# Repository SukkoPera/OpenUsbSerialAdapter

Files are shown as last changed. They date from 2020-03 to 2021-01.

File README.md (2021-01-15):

# OpenUsbSerialAdapter
OpenUsbSerialAdapter is an Open Hardware USB to TTL-level Serial converter.

Board

### Summary
An infinite number of different models of USB to TTL-level serial converters can be found on every online shop, many of which even cost less than 1€ shipped from China, so why make one more? There are a few reasons:
- Many of them are missing the DTR and RTS signals (or at least do not break them out so that they can be used). At least one of these signals is necessary for programming Arduino boards through the serial port and, since this makes up for 90% of my use of USB to serial converters, I find this pretty annoying.
- Most of these cheap converters claim to be both 5V and 3.3V serial level compatible, but all most of them actually do is just use 3.3V signalling, which *usually* also works fine with boards that work at 5V, but still it is a bit of a hack.
- None of these converters has a decent 3.3V regulator onboard, usually being able to provide only a few tens of milliamperes on the 3.3V power pin (and not even all of them have one). This is too little for some uses, like powering an ESP8266 module for instance, and is the source of maaany of the problems users report with that chip.
- Finding Windows and OSX drivers for some of these modules is a nightmare.
- Not to mention the infamous FTDI-gate...

So, when I came across a USB to Serial chip ([Microchip MCP2200](http://ww1.microchip.com/downloads/en/DeviceDoc/200022228D.pdf)) that had RTS/CTS signals and claimed not to need any particular drivers, I decided to have a go at designing the one converter to rule them all. I tried to consider every possible feature during the design, but in any case I am releasing this as Open Hardware, so everybody can customize it so that it fully suits their needs.

### Features
- Real support for both 3.3V and 5V signalling and power output levels
- RX/TX leds
- Protection resistors for RX/TX inversion
- RX/TX pull-up resistors (optional)
- Can provide up to 1A current on the 3.3V power output pin (This will actually be less as it will be limited by USB)
- Hardware Flow Control pins (RTS/CTS, RTS can be used for the initial reset for Arduino programming)
- Speed up to 1000 kBaud/s
- Uses USB HID capabilities, which means it needs no drivers on Windows/OSX (This has to confirmed, as I only run Linux)
- Configurable product/manufacturer strings and PID/VID
- Ability to invert the polarity of the RX/TX signals
- Compact form factor (about the size of a standard thumb drive)
- Cheap (total BOM cost is less than 3€) and easy to DIY-build (about 20 common components, SMD soldering ability is required, but all components are 0805 or larger)

### Assembly and Configuration
Solder all components to the board in the order you prefer. You have some options:
- R3 and R4 are the RX/TX inversion protection resistors. I used 100 ohm for these, which works fine in my tests, but this value was improvised rather than calculated. You might want to increase them up to 1k for additional safety. In rare cases, you might want to replace them with 0 ohm/solder blobs, but this might be harmful for the main chip or for the device it is connected to. Do this at your risk.
- R5 and R6 are the RX/TX pull-up resistors. Usually these are not necessary, so you might want to skip them. Note that R7 is mandatory instead.

The adapter is somewhat configurable. On Windows you can use [the official Microchip Configuration Utility](http://ww1.microchip.com/downloads/en/DeviceDoc/MCP2200%20Configuration%20Utility%20v1.3.1.zip). On Linux (and OSX?) you can use [a quick replacement I put together](https://github.com/SukkoPera/OpenUsbSerialAdapter/tree/master/confutil), or [this other one](https://github.com/andrasbiro/mcp2200hid-linux). The latter is also capable of changing the USB product/manufacturer strings and PID/VID.

Note that the factory settings of the chip will NOT make the RX/TX leds blink on traffic, you will have to enable that through the configuration utility. Another apparent oddity is that you need to turn Hardware Flow Control OFF in order to use the adapter for Arduino programming.

Signal polarity inversion can also be enabled through the Configuration Utility.

### Usage
Just plug the converter into a free USB port of your computer. On Linux a /dev/ttyACMx device should pop up within seconds. On other Operating Systems... You are on your own :). In theory, it should not need any dedicated drivers, but I saw there are some [on the MCP2200 product page](https://www.microchip.com/wwwproducts/en/en546923), so you can get them from there, in case.

### Releases
If you want to get this board produced, you are recommended to get [the latest release](https://github.com/SukkoPera/OpenUsbSerialAdapter/releases) rather than the current git version, as the latter might be under development and is not guaranteed to be working.

Every release is accompanied by its Bill Of Materials (BOM) file and any relevant notes about it, which you are recommended to read carefully.

### License
The OpenUsbSerialAdapter documentation, including the design itself, is copyright &copy; SukkoPera 2020.

OpenUsbSerialAdapter is Open Hardware licensed under the [CERN OHL v. 1.2](http://ohwr.org/cernohl).

You may redistribute and modify this documentation under the terms of the CERN OHL v.1.2. This documentation is distributed *as is* and WITHOUT ANY EXPRESS OR IMPLIED WARRANTIES whatsoever with respect to its functionality, operability or use, including, without limitation, any implied warranties OF MERCHANTABILITY, SATISFACTORY QUALITY, FITNESS FOR A PARTICULAR PURPOSE or infringement. We expressly disclaim any liability whatsoever for any direct, indirect, consequential, incidental or special damages, including, without limitation, lost revenues, lost profits, losses resulting from business interruption or loss of data, regardless of the form of action or legal theory under which the liability may be asserted, even if advised of the possibility or likelihood of such damages.

A copy of the full license is included in file [LICENSE.pdf](LICENSE.pdf), please refer to it for applicable conditions. In order to properly deal with its terms, please see file [LICENSE_HOWTO.pdf](LICENSE_HOWTO.pdf).

The contact points for information about manufactured Products (see section 4.2) are listed in file [PRODUCT.md](PRODUCT.md).

Any modifications made by Licensees (see section 3.4.b) shall be recorded in file [CHANGES.md](CHANGES.md).

The Documentation Location of the original project is https://github.com/SukkoPera/OpenUsbSerialAdapter/.

### Support the Project
If you want to support the project, you can order the boards from PCBWay through this link:

PCB from PCBWay (https://www.pcbway.com/project/shareproject/OpenUsbSerialAdapter_V2.html)

You get my gratitude and cheap, good quality PCBs, professionally-made. I get some credit that will help with this and [other projects](https://www.pcbway.com/project/member/shareproject/?bmbid=41100). You won't even have to worry about the various PCB options, it's all pre-configured for you!

If you still have to register to that site, [you can use this link](https://www.pcbway.com/setinvite.aspx?inviteid=41100) to get some bonus initial credit (and yield me some more).

You can also buy me a coffee if you want:

<a href='https://ko-fi.com/L3L0U18L' target='_blank'>Buy Me a Coffee at ko-fi.com</a>

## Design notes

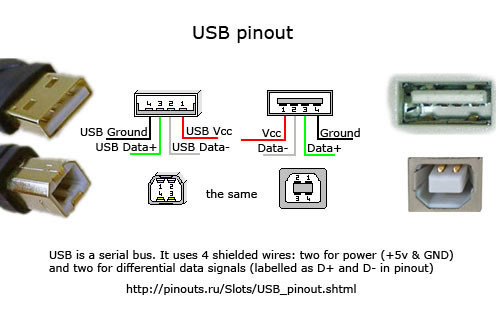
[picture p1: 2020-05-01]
doc/usb-pinout.jpg

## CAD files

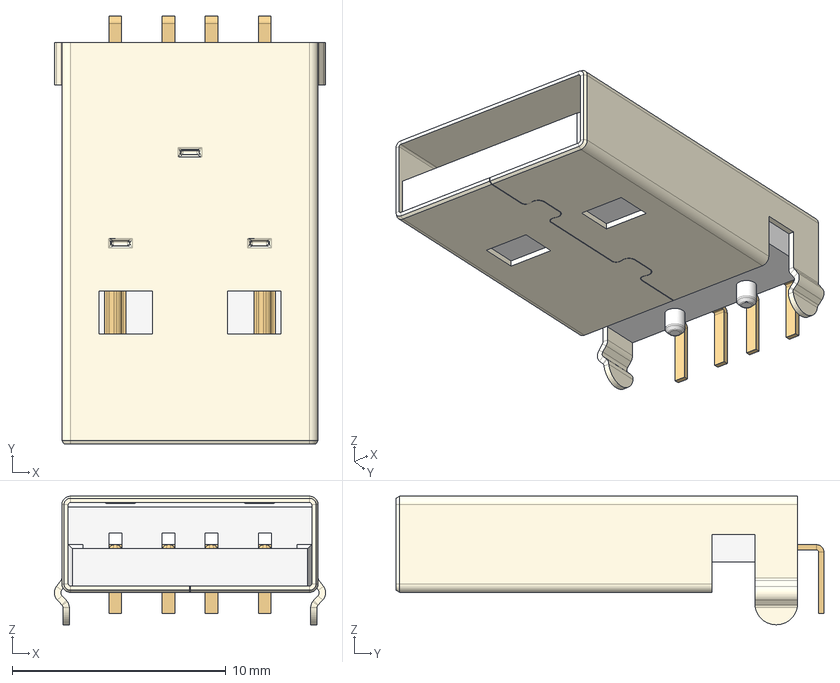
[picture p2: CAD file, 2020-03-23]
3dModels/USB-A Right Angle Solder Plug.stp
12.7 x 20.0 x 6.02 mm
USB-A Right Angle Solder Plug Shell
USB-A Right Angle Solder Plug Inlay
USB-A Right Angle Solder Plug Contact 1 x 2
USB-A Right Angle Solder Plug Contact 2 x 2

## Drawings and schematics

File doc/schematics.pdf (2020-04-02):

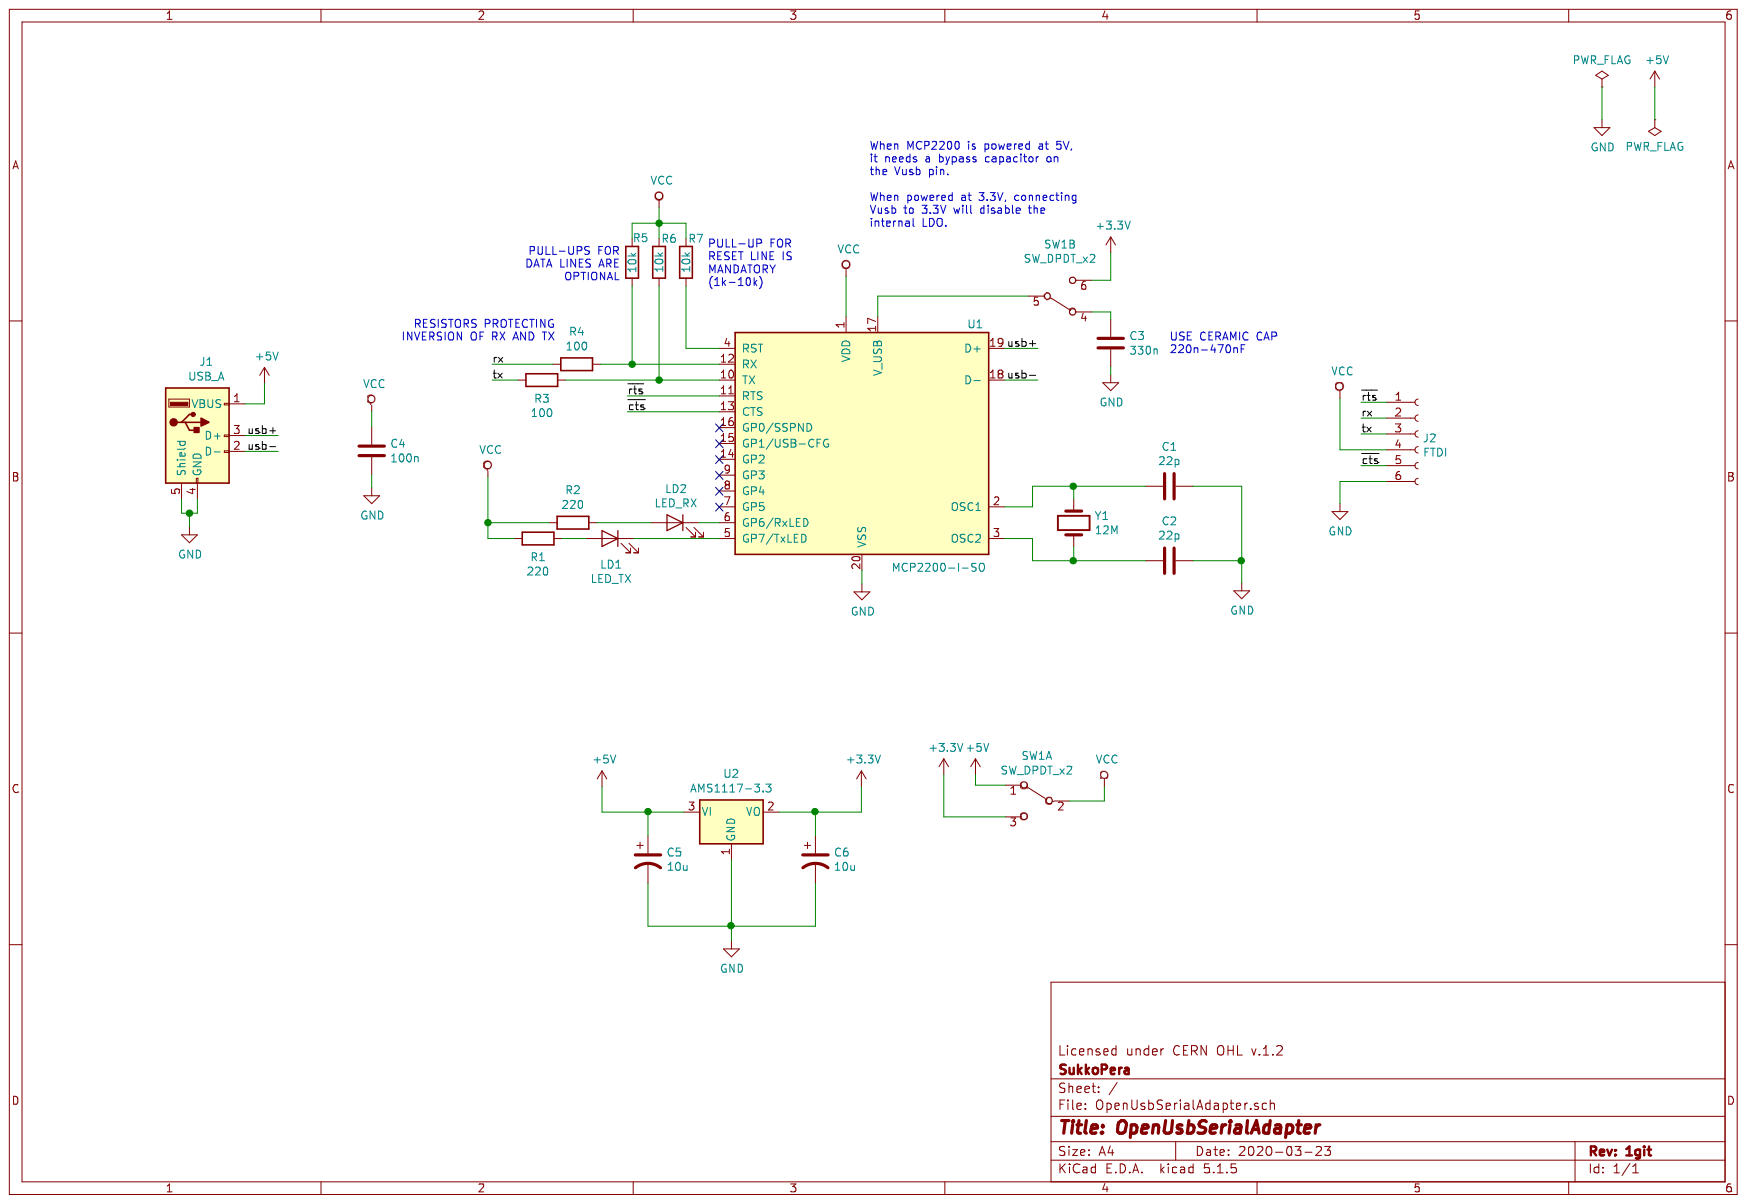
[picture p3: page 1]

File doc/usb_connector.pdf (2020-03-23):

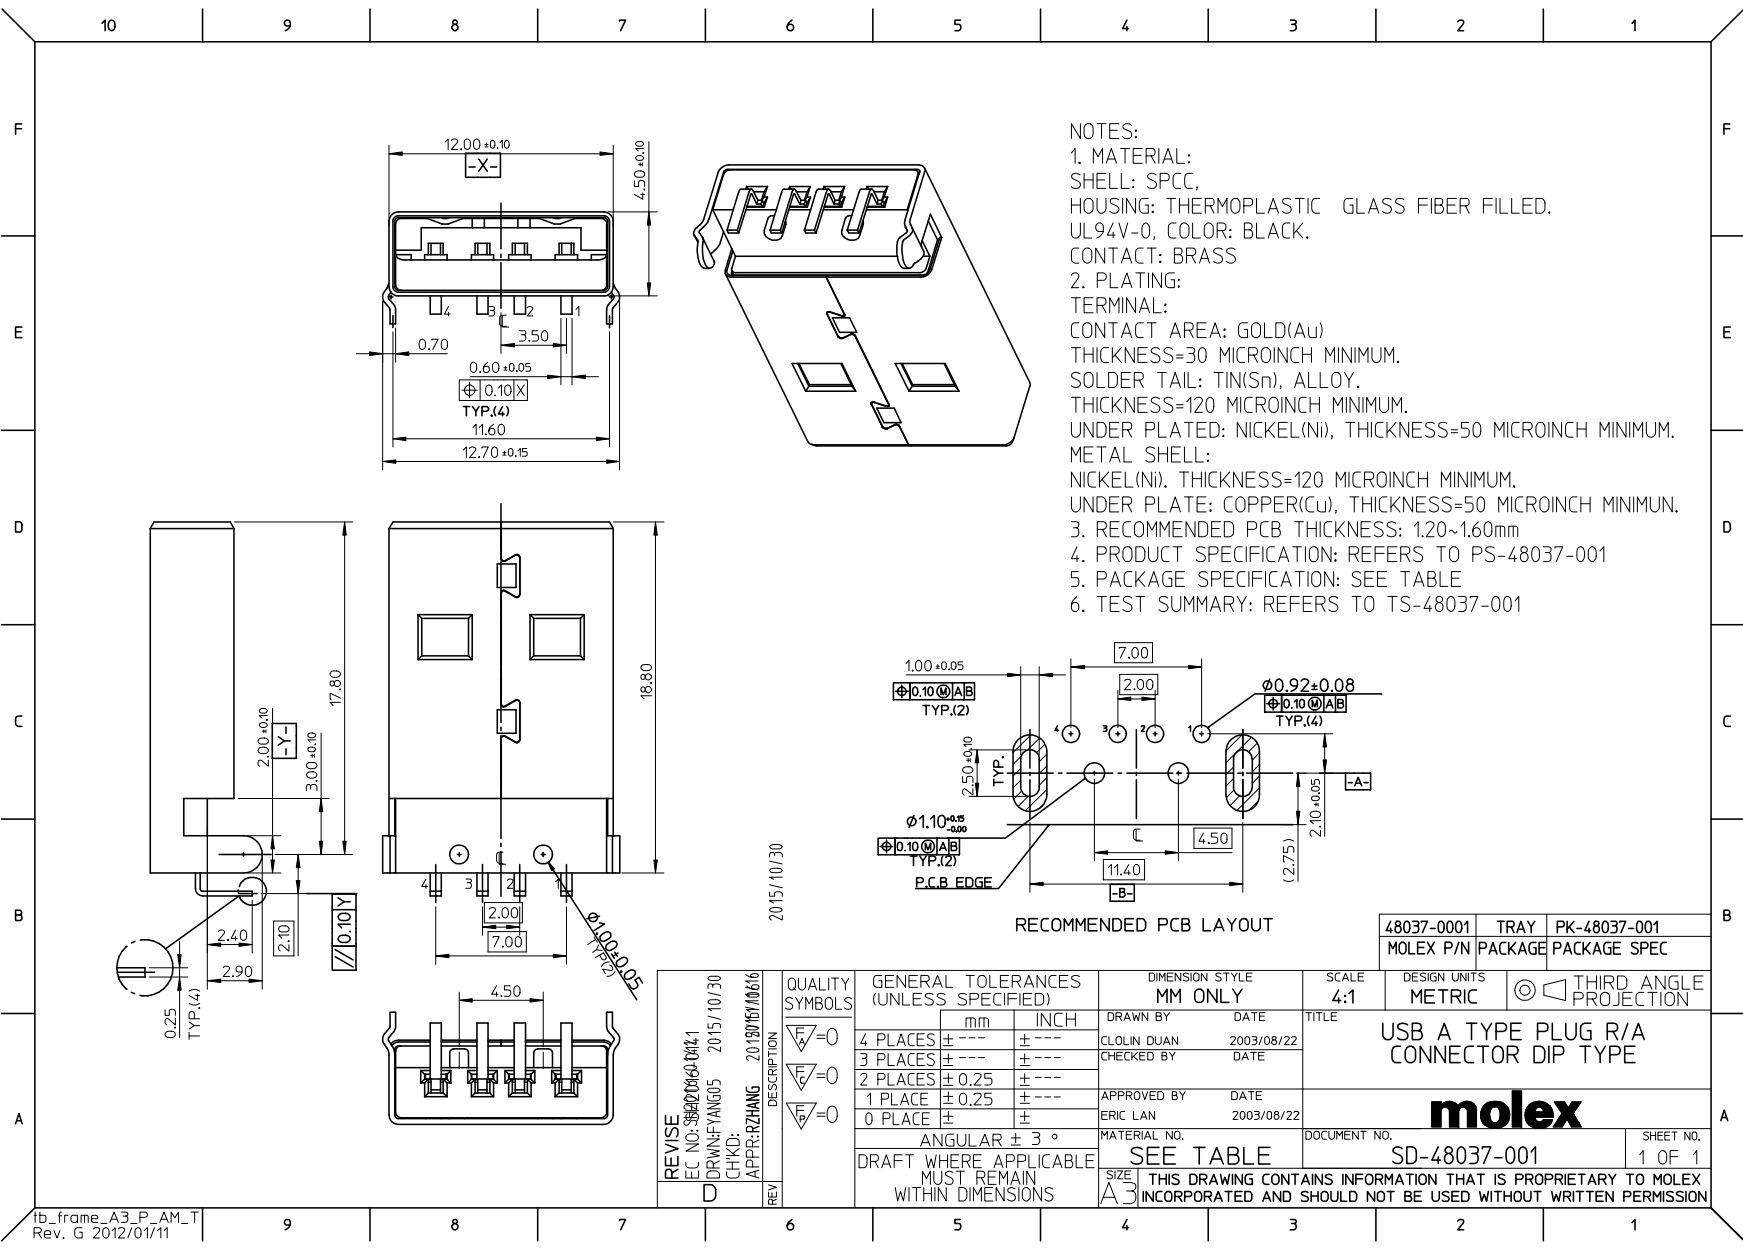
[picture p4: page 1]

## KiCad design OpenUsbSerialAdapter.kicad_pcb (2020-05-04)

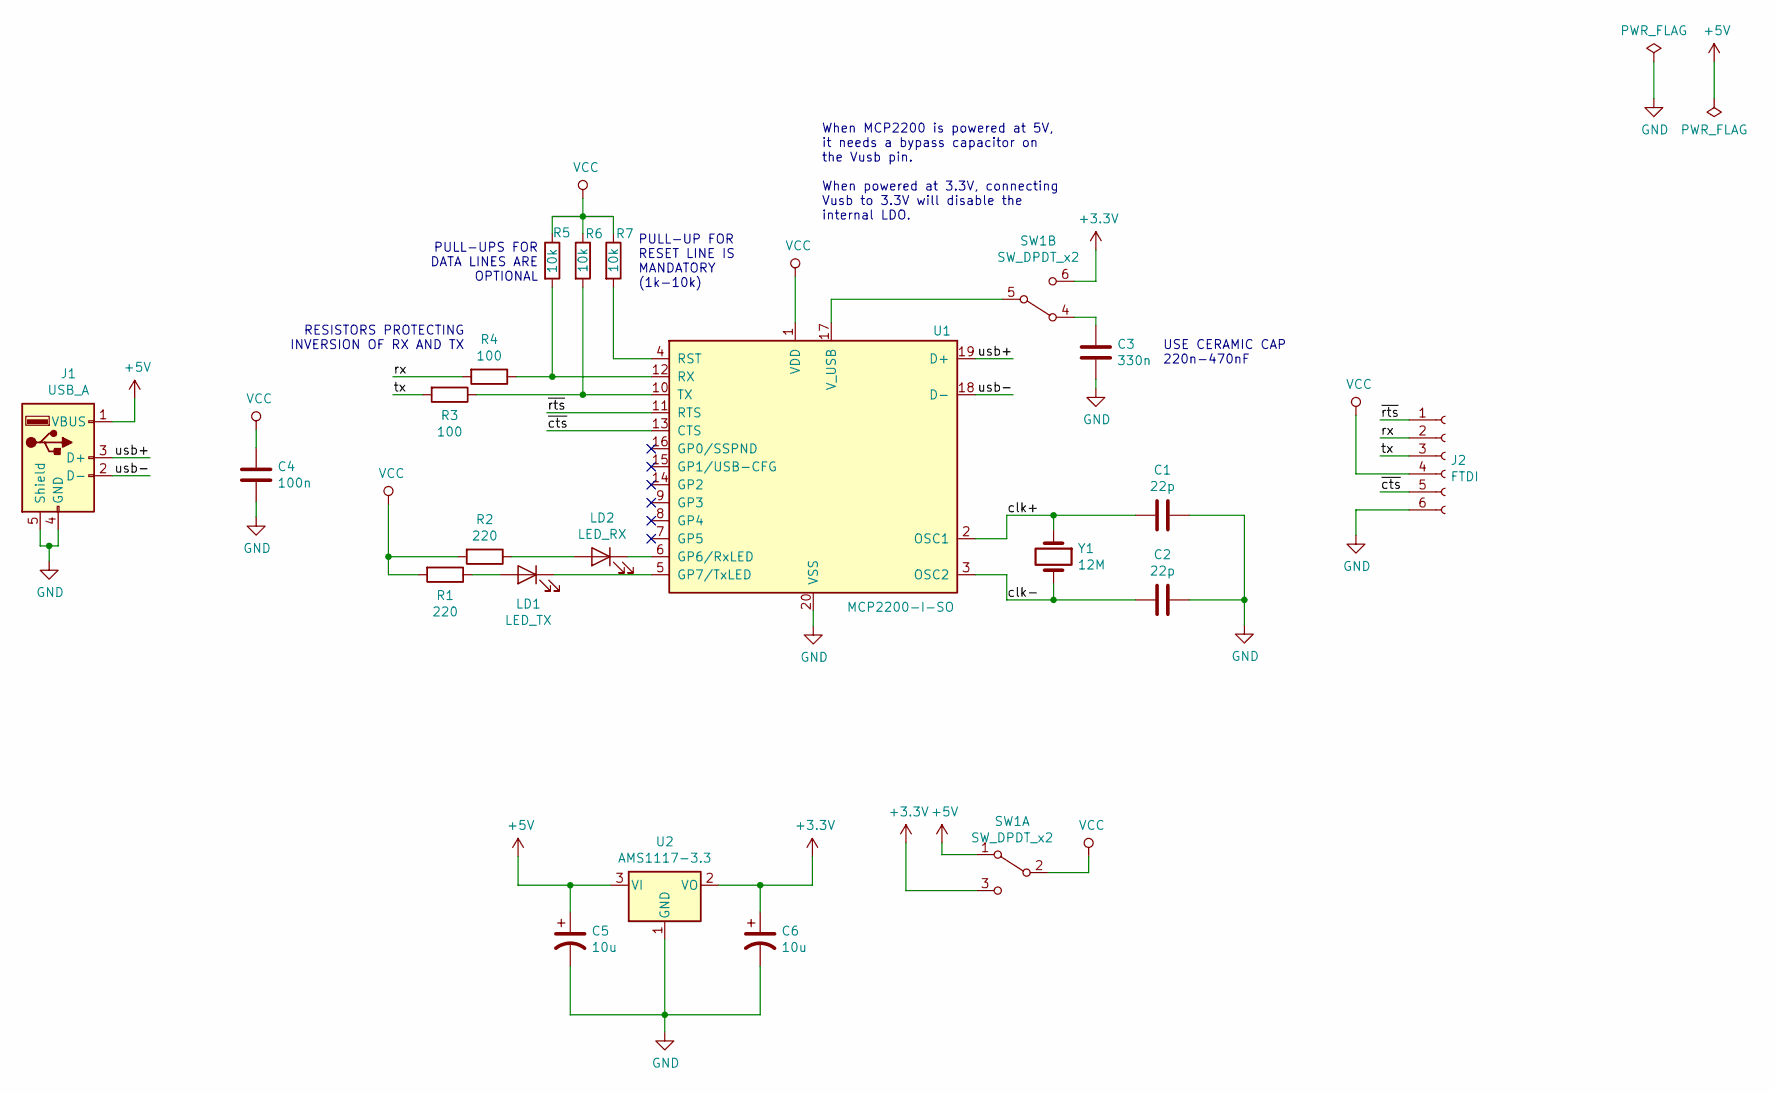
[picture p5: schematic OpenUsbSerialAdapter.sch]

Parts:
C1, C2: 22p; C_0805_2012Metric_Pad1.15x1.40mm_HandSolder
C3: 330n; C_1206_3216Metric_Pad1.42x1.75mm_HandSolder
C4: 100n; C_0805_2012Metric_Pad1.15x1.40mm_HandSolder
C5, C6: 10u; CP_EIA-3216-18_Kemet-A_Pad1.58x1.35mm_HandSolder
J1: USB_A; USB_A_Molex_48037
J2: FTDI; PinHeader_1x06_P2.54mm_Vertical
LD1: LED_TX; LED_0805_2012Metric_Pad1.15x1.40mm_HandSolder
LD2: LED_RX; LED_0805_2012Metric_Pad1.15x1.40mm_HandSolder
R1, R2: 220; R_0805_2012Metric_Pad1.15x1.40mm_HandSolder
R3, R4: 100; R_0805_2012Metric_Pad1.15x1.40mm_HandSolder
R5, R6, R7: 10k; R_0805_2012Metric_Pad1.15x1.40mm_HandSolder
SW1: SW_DPDT_x2; SW_DPDT
U1: MCP2200-I-SO; SOIC-20W_7.5x12.8mm_P1.27mm
U2: AMS1117-3.3; SOT-223-3_TabPin2
Y1: 12M; Crystal_HC49-U_Vertical

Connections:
+3V3: C6.1, SW1.3 (C), SW1.6 (C), U2.2 (VO)
+5V: C5.1, J1.1 (VBUS), SW1.1 (A), U2.3 (VI)
/clk+: C1.2, U1.2 (OSC1), Y1.1
/clk-: C2.2, U1.3 (OSC2), Y1.2
/rx: J2.2, R4.2
/tx: J2.3, R3.2
/usb+: J1.3 (D+), U1.19 (D+)
/usb-: J1.2 (D-), U1.18 (D-)
/~cts: J2.5, U1.13 (CTS)
/~rts: J2.1, U1.11 (RTS)
GND: C1.1, C2.1, C3.2, C4.2, C5.2, C6.2, J1.4 (GND), J1.5 (Shield), J2.6, U1.20 (VSS), U2.1 (GND)
unnamed: C3.1, SW1.4 (A)
unnamed: LD1.1 (K), U1.5 (GP7/TxLED)
unnamed: LD1.2 (A), R1.1
unnamed: LD2.1 (K), U1.6 (GP6/RxLED)
unnamed: LD2.2 (A), R2.1
unnamed: R3.1, R6.2, U1.10 (TX)
unnamed: R4.1, R5.2, U1.12 (RX)
unnamed: R7.2, U1.4 (RST)
unnamed: SW1.5 (B), U1.17 (V_USB)
VCC: C4.1, J2.4, R1.2, R2.2, R5.1, R6.1, R7.1, SW1.2 (B), U1.1 (VDD)

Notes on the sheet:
PULL-UPS FOR DATA LINES ARE OPTIONAL
RESISTORS PROTECTING INVERSION OF RX AND TX
PULL-UP FOR RESET LINE IS MANDATORY (1k-10k)
USE CERAMIC CAP 220n-470nF
When MCP2200 is powered at 5V, it needs a bypass capacitor on the Vusb pin. When powered at 3.3V, connecting Vusb to 3.3V will disable the internal LDO.

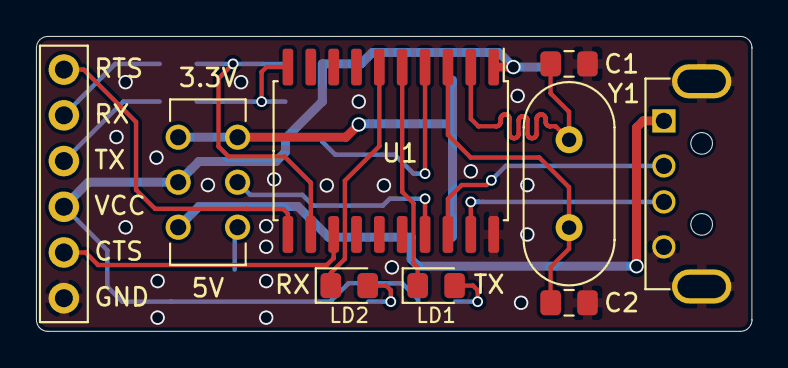
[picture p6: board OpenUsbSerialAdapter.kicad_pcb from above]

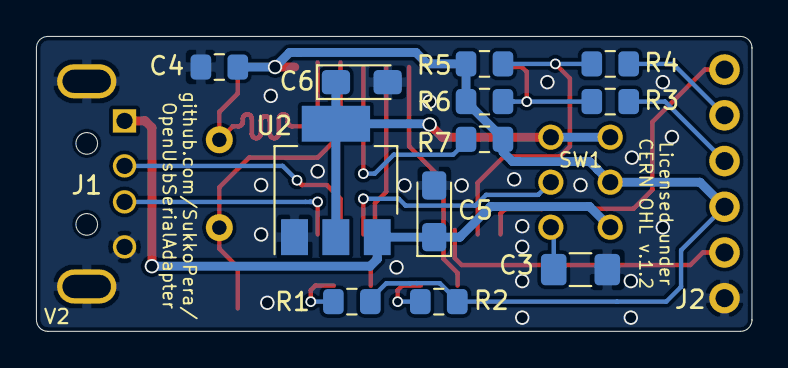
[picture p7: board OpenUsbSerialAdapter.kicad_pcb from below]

Board: 2 copper layers, 39.8 x 16.4 mm, 21 parts (12 on the bottom side), 21 nets.

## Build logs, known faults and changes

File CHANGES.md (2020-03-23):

## CHANGES

Any modifications to the OpenUsbSerialAdapter design and documentation made by any Licensee MUST be noted in this file, as per *section 3.4.b* of the [license](LICENSE.pdf).

### (Date) - (Author)
(Description)

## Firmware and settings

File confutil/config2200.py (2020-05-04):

#!/usr/bin/env python3

# This program was made using information presented in MCP doc
# It can manipulate all the chip features except:
# - Vendor ID
# - Product ID
# - Manufacturer String
# - Product String
#
# as no instruction are presented about how to do this

import sys
import argparse

import hid

vid = 0x04d8
pid = 0x00df

CLOCK_HZ = 12000000

# Config_Alt_Options
CAO_HWFLOW = 0
CAO_INVERT = 1
CAO_LEDX = 5
CAO_TXTGL = 6
CAO_RXTGL = 7

# Config_Alt_Pins
CAP_TXLED = 2
CAP_RXLED = 3
CAP_USBCFG = 6
CAP_SSPND = 7

parser = argparse.ArgumentParser (description = 'MCP2200 Configuration Utility', epilog = "Options take \"on\" or \"off\" values except where noted")
parser.add_argument ('-f', '--flow', type = str, help = 'Hardware Flow Control (CTS/RTS, turn OFF for Arduino programming)')
parser.add_argument ('-i', '--invert', type = str, help = 'Level Inversion')
parser.add_argument ('-s', '--suspend', type = str, help = 'Suspend Pin')
parser.add_argument ('-u', '--usbcfg', type = str, help = 'USB Configured Pin')
parser.add_argument ('-l', '--leds', type = str, help = 'Led Pins Behaviour (off, slow, fast, toggle)')
parser.add_argument ('-b', '--baudrate', type = str, help = 'Serial speed to be used')
args = parser.parse_args ()

def val2bool (v):
	return True if v.lower () == "on" else False

with hid.Device (vid, pid) as h:
	print (f'Device manufacturer: {h.manufacturer}')
	print (f'Product: {h.product}')
	print (f'Serial Number: {h.serial}')

	# Read conf
	h.write (bytes ([0x80] + [0x00] * 15))
	rep = h.read (16)
	if rep[0] != 0x80:
		print ("Bad reply: %s" % str (rep))
	else:
		ioBmap = rep[4]
		confAltPins = rep[5]
		ioDefVal = rep[6]
		confAltOpts = rep[7]
		div = (rep[8] << 8) | rep[9]
		baud = CLOCK_HZ / (div + 1)
		ioPortVal = rep[10]

		print ("Hardware Flow Control: %s" % ("Enabled" if confAltOpts & (1 << CAO_HWFLOW) else "Disabled"))
		print ("Level Inversion: %s" % ("Enabled" if confAltOpts & (1 << CAO_INVERT) else "Disabled"))
		print ("GP0 Function: %s" % ("USB Suspend Signal" if confAltPins & (1 << CAP_SSPND) else "GPIO"))
		print ("GP1 Function: %s" % ("USB Configured Signal" if confAltPins & (1 << CAP_USBCFG) else "GPIO"))
		print ("GP6 Function: %s" % ("RXLED" if confAltPins & (1 << CAP_RXLED) else "GPIO"))
		print ("GP7 Function: %s" % ("TXLED" if confAltPins & (1 << CAP_TXLED) else "GPIO"))
		print ("GPIO Bitmap (0 = out, 1 = in): {0:08b}".format (ioBmap))
		print ("Default GPIO Values (0 = low, 1 = high): {0:08b}".format (ioDefVal))
		print ("Current GPIO Values (0 = low, 1 = high): {0:08b}".format (ioPortVal))
		print ("RX Led: %s" % ("Toggle" if confAltOpts & (1 << CAO_RXTGL) else "Blink %s" % ("slow" if confAltOpts & (1 << CAO_LEDX) else "fast")))
		print ("TX Led: %s" % ("Toggle" if confAltOpts & (1 << CAO_TXTGL) else "Blink %s" % ("slow" if confAltOpts & (1 << CAO_LEDX) else "fast")))
		print ("Baud Rate: %u bps" % baud)


	newIoBmap = ioBmap
	newConfAltPins = confAltPins
	newIoDefVal = ioDefVal
	newConfAltOpts = confAltOpts
	newDiv = div
	
	if args.flow is not None:
		if val2bool (args.flow):
			newConfAltOpts |= (1 << CAO_HWFLOW)
		else:
			newConfAltOpts &= ~(1 << CAO_HWFLOW)
	
	if args.invert is not None:
		if val2bool (args.invert):
			newConfAltOpts |= (1 << CAO_INVERT)
		else:
			newConfAltOpts &= ~(1 << CAO_INVERT)
	
	if args.suspend is not None:
		if val2bool (args.suspend):
			newConfAltPins |= (1 << CAP_SSPND)
		else:
			newConfAltPins &= ~(1 << CAP_SSPND)
	
	if args.usbcfg is not None:
		if val2bool (args.usbcfg):
			newConfAltPins |= (1 << CAP_USBCFG)
		else:
			newConfAltPins &= ~(1 << CAP_USBCFG)

	if args.leds:
		leds = args.leds.lower ()
		if leds == "off":
			newConfAltPins &= ~((1 << CAP_RXLED) | (1 << CAP_TXLED))
		elif leds == "toggle":
			newConfAltPins |= ((1 << CAP_RXLED) | (1 << CAP_TXLED))
			newConfAltOpts |= ((1 << CAO_RXTGL) | (1 << CAO_TXTGL))
		elif leds == "fast":
			newConfAltPins |= ((1 << CAP_RXLED) | (1 << CAP_TXLED))
			newConfAltOpts &= ~((1 << CAO_RXTGL) | (1 << CAO_TXTGL) | (1 << CAO_LEDX))
		elif leds == "slow":
			newConfAltPins |= ((1 << CAP_RXLED) | (1 << CAP_TXLED))
			newConfAltOpts &= ~((1 << CAO_RXTGL) | (1 << CAO_TXTGL))
			newConfAltOpts |= (1 << CAO_LEDX)
		else:
			print ("Cannot parse --leds argument: %s" % args.leds, file = sys.stderr)
			sys.exit (10)

	if args.baudrate:
		newDiv = CLOCK_HZ // int (args.baudrate) - 1		

	cmd = [0x10, 0x00, 0x00, 0x00, newIoBmap, newConfAltPins, newIoDefVal, newConfAltOpts, (newDiv & 0xFF00) >> 8, (newDiv & 0xFF)]
	while len (cmd) < 16:
		cmd.append (0x00)
	print (cmd)

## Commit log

2020-03-22 PCB is routed
    [OpenUsbSerialAdapter.kicad_pcb, OpenUsbSerialAdapter.sch]
2020-03-23 Done! (Again...)
    [OpenUsbSerialAdapter.kicad_pcb, OpenUsbSerialAdapter.sch]
2020-03-23 Some refinements
    [OpenUsbSerialAdapter.kicad_pcb, OpenUsbSerialAdapter.sch]
2020-03-23 Final touches
    [OpenUsbSerialAdapter.kicad_pcb, OpenUsbSerialAdapter.sch]
2020-03-24 Move track so that it looks better
    [OpenUsbSerialAdapter.kicad_pcb]
2020-04-02 Add schematics PDF
2020-04-03 Tune quartz tracks length
    [OpenUsbSerialAdapter.kicad_pcb, OpenUsbSerialAdapter.sch]
2020-04-03 Final polishing
    [OpenUsbSerialAdapter.kicad_pcb]
2020-04-04 Update version numbers
    [OpenUsbSerialAdapter.kicad_pcb, OpenUsbSerialAdapter.sch]
2020-05-01 Fix pin order of USB connector, sigh...
    [OpenUsbSerialAdapter.kicad_pcb]
2020-05-04 Fix led labels, grrrrr!
    [OpenUsbSerialAdapter.kicad_pcb]

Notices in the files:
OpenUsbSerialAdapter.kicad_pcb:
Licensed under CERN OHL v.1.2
